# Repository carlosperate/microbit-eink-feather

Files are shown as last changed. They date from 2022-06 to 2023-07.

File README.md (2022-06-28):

# micro:bit eInk Feather Adaptor

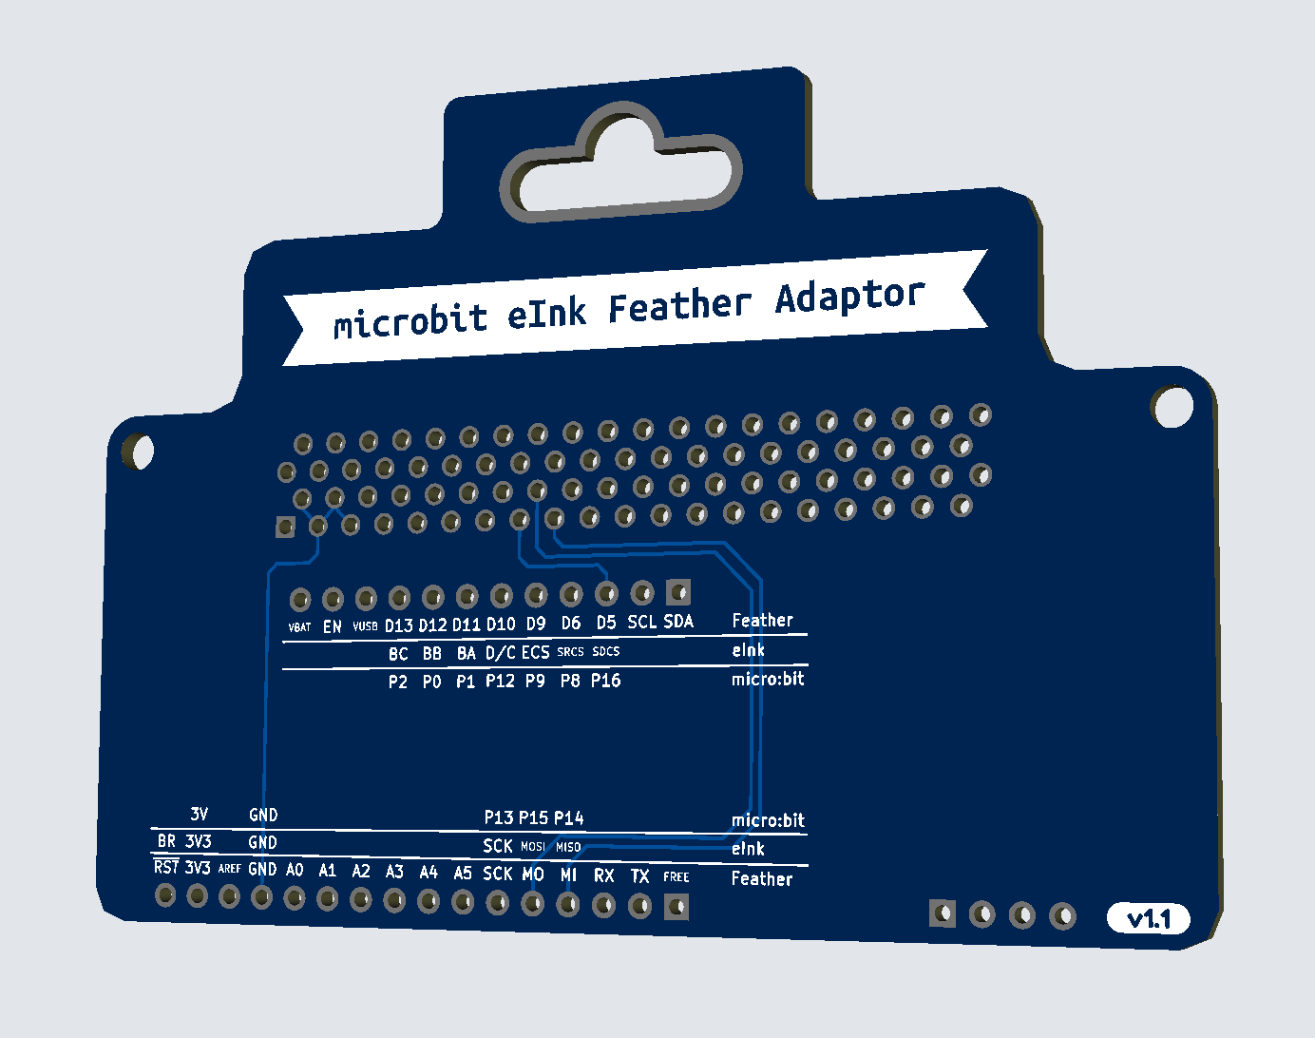
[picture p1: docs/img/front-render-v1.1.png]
front-render-v1 0


This is a simple FeatherWing to micro:bit adaptor board designed specifically
for the Adafruit 2.9" Grayscale eInk / ePaper Display FeatherWing:
https://www.adafruit.com/product/4777

## Repository Contents

- **datasheets**: Datasheets for the components used in this adaptor board
- **docs**: Documentation related to this adaptor board
- **firmware**: Arduino Skectch to test the eInk FeatherWing with a micro:bit
- **hardware**: The KiCad project files
- **output**: Project output files, like the BOM, schematic PDFs, etc.
    - **interactive_bom**: BOM output from the
      [Interactive HTML BOM](https://github.com/openscopeproject/InteractiveHtmlBom)
      KiCad plugin.
    - **pdf**: Schematic PDFs.
    - **production**: Gerber and drill files.

## Documentation

- Pinout connections for the adaptor board: [docs/pins.md](docs/pins.md)
- [eInk FeatherWing product page](https://www.adafruit.com/product/4777)
- [Adafruit documentation for the eInk FeatherWing](https://learn.adafruit.com/adafruit-eink-display-breakouts/grayscale-29-overview)
- [Documentation for the family of Adafruit 2.9" eInk Display Breakouts and FeatherWings](https://learn.adafruit.com/adafruit-2-9-eink-display-breakouts-and-featherwings/)
- Project Changelog: [CHANGELOG.md](CHANGELOG.md)

## License & Attributions

The Arduino test sketch is based on the
[Adafruit EDP ThinkInk_gray4 example][6], with [MIT License][7].

The micro:bit edge connector is [MIT Licensed][8] and comes from:
https://github.com/anthonykirby/kicad_microbit_connector

This project has been based on this FeatherWing template:
https://github.com/ppelleti/FeatherWing-template-KiCad

The FeatherWing template and the rest of the repository (except where stated
otherwise) is licensed under [the same terms as the KiCad libraries][9],
which is the [CC-BY-SA 4.0][10] license, with an exception that says that
electronic designs based on this repository are not bound by the attribution
and share-alike conditions.

[6]: https://github.com/adafruit/Adafruit_EPD/blob/4.4.3/examples/ThinkInk_gray4/ThinkInk_gray4.ino
[7]: firmware/eink_feather_test/LICENSE
[8]: hardware/microbit_connector/LICENSE
[9]: https://forum.kicad.info/t/kicad-library-licensing/7856
[10]: https://creativecommons.org/licenses/by-sa/4.0/legalcode

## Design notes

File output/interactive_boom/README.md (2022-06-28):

# Interactive BOM

This BOM has been created with the
[Interactive HTML BOM](https://github.com/openscopeproject/InteractiveHtmlBom)
plugin.

To preview this HTML online you can use this link:
[online ibom.min.html](https://refined-github-html-preview.kidonng.workers.dev/carlosperate/microbit-eink-feather/raw/main/output/interactive_boom/ibom.min.html)

The node `package.json` file contains an npm script to minify the output of
the plugin:
```
npm run minify
```

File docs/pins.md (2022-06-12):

# Pins

## Board Pin Routing

This table show the feather to micro:bit pins connections.

None of the micro:bit pins selected have other functionality (like the
matrix display or buttons). The P0, P1, and P2 micro:bit pins have weak pull
ups and so, they have been assigned to the eInk feather buttons, as that should
not affect their operation.

| Feather ⬅️ | eInk | micro:bit pin | | Feather ➡️ | eInk | micro:bit pin |
|---|---|---|-|---|---|---|
| RST | RST | - | | | | |
| 3.3V | 3V | - | | | | |
| Aref | - | - | | | | |
| GND | GND | - | | | | |
| A0 | - | - | | Bat | - | - |
| A1 | - | - | | En | - | - |
| A2 | - | - | | VUSB  | - | - |
| A3 | - | - | | D13 | C Button | P2 |
| A4 | - | - | | D12 | B Button | P0 |
| A5 | - | - | | D11 | A Button | P1 |
| SCK | SCK | P13 (SCK) | | D10 | D/C | P12 |
| MO | MOSI | P15 (MOSI) | | D9 | ECS | P9 |
| MI | MISO | P14 (MISO) | | D6 | SRCS | P8 |
| RX | - | - | | D5 | SDCS | P16 |
| TX | - | - | | SCL | - | - |
| Free | - | - | | SDA | - | - |

Feather pins:
- RST - Connected to the Reset button in the eInk feather
- SCK - SPI Clock
- MO - SPI MOSI from microcontroller to feather
- MI - SPI MISO from feather to microcontroller
- Button A/B/C - Connected to the three top button in the feather
- D/C - The eInk Data/Command pin, required for controlling the display
- ECS - Eink SPI Chip Select
- SRCS - SRAM SPI Chip Select
- SDCS - SD Card SPI Chip Select

eInk feather pinout from:
https://learn.adafruit.com/adafruit-eink-display-breakouts/pinouts-2

## Pinouts

This section contains the micro:bit V2 and Generic Feather pinouts for
reference.

### micro:bit V2 pinout

From: https://tech.microbit.org/hardware/edgeconnector/#edge-connector-pins

micro:bit pinout

### Feather pinout

This is the generic feather pinout, which might change slightly depending on
the board. From:
https://learn.adafruit.com/adafruit-feather/feather-specification#pin-naming-3096825-19

| Feather left header | Feather right header |
|---|---|
| Rst  | |
| 3.3V | |
| Aref | |
| GND  | |
| A0 | Bat  |
| A1 | En |
| A2 | VUSB |
| A3 | D13  |
| A4 | D12  |
| A5 | D11  |
| SCK  | D10  |
| MO | D9 |
| MI | D6 |
| RX | D5 |
| TX | SCL  |
| Free | SDA  |

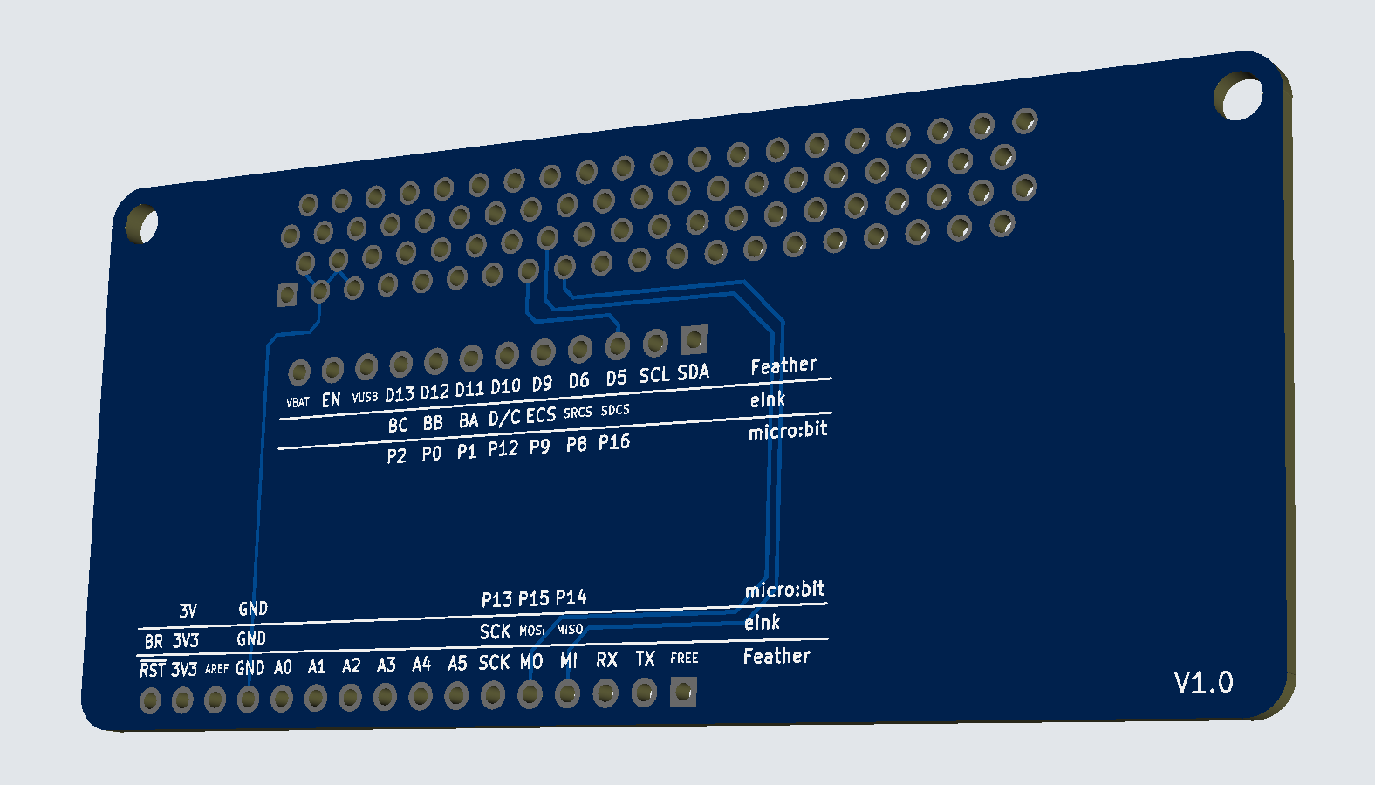
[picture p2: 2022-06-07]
docs/img/front-render-v1.0.png

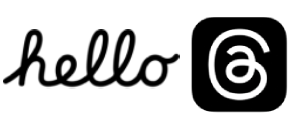
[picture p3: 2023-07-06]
firmware/eink_feather_sd_bmp/hello.bmp

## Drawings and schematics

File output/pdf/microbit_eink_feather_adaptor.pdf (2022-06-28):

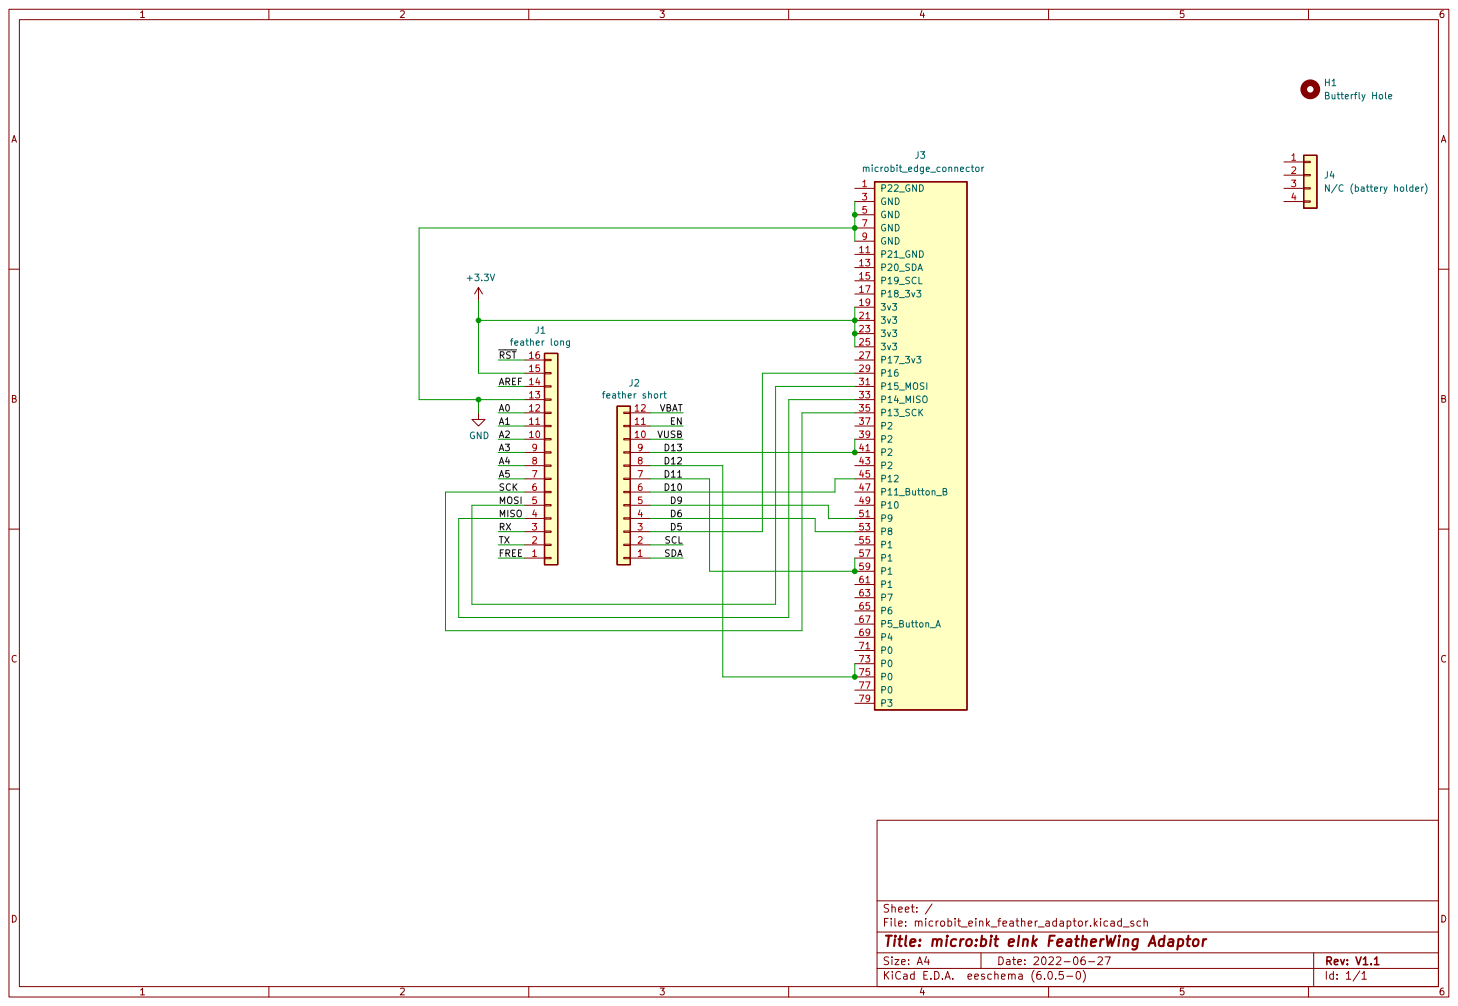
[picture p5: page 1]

File: microbit_eink_feather_adaptor.kicad_sch Sheet: /
Id: 1/1 Title: micro:bit eInk FeatherWing Adaptor

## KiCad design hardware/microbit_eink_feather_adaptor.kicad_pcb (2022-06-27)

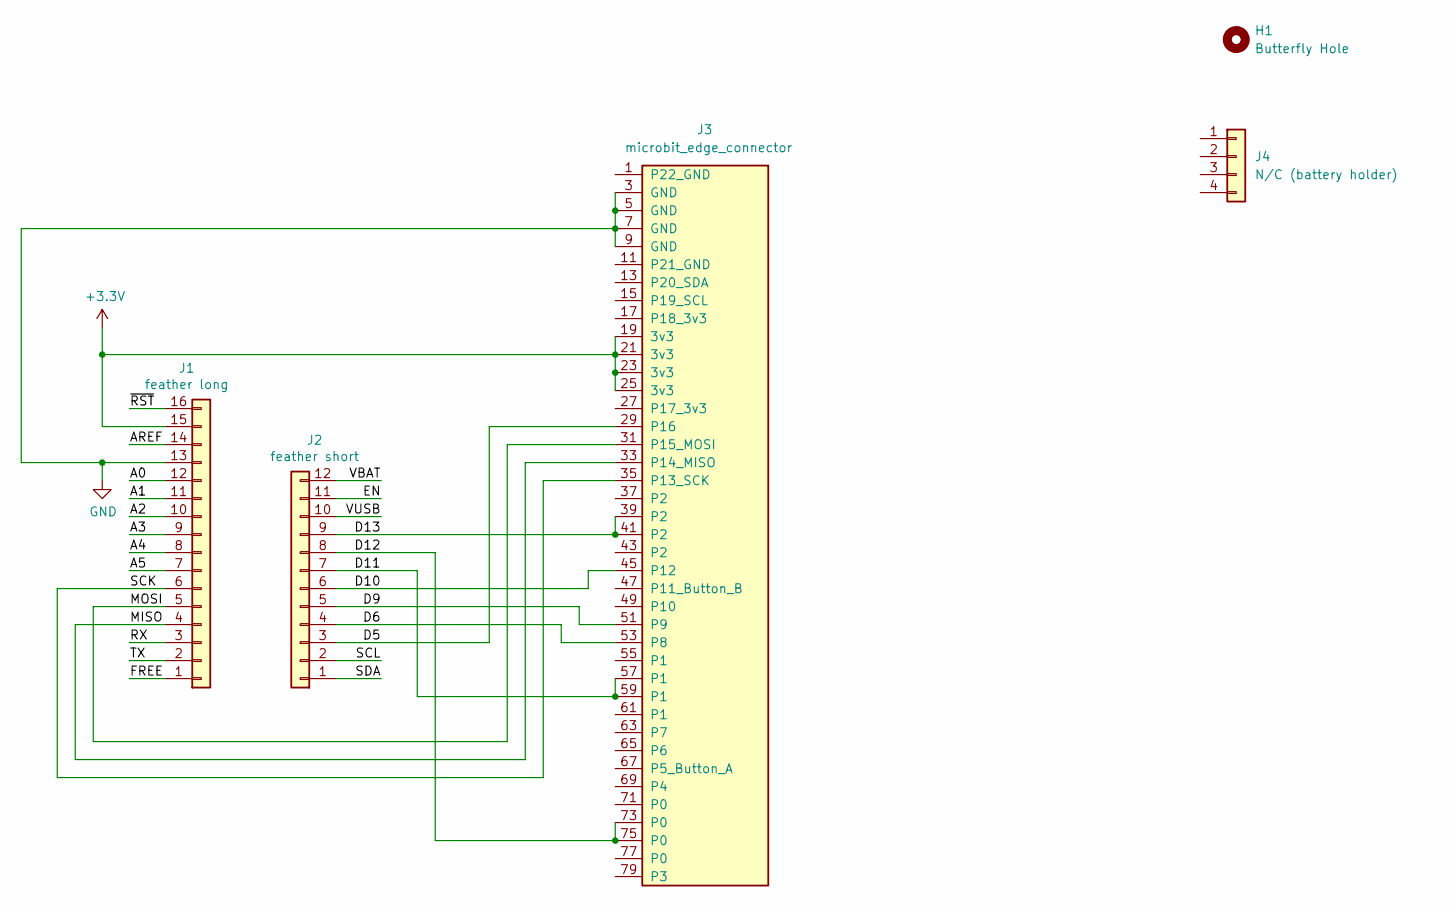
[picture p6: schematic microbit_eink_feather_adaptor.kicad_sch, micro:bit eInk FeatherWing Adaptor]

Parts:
H1: Butterfly Hole; butterfly_hole
J1: feather long; PinHeader_1x16_P2.54mm_Vertical
J2: feather short; PinHeader_1x12_P2.54mm_Vertical
J3: microbit_edge_connector; 4UCON_10156_2x40_P1.27mm_Socket_Horizontal
J4: N/C (battery holder); PinHeader_1x04_P2.54mm_Vertical

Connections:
+3V3: J1.15, J3.19 (3v3), J3.21 (3v3), J3.23 (3v3), J3.25 (3v3)
/A0: J1.12
/A1: J1.11
/A2: J1.10
/A3: J1.9
/A4: J1.8
/A5: J1.7
/AREF: J1.14
/D5: J2.3, J3.29 (P16)
/D6: J2.4, J3.53 (P8)
/D9: J2.5, J3.51 (P9)
/D10: J2.6, J3.45 (P12)
/D11: J2.7, J3.57 (P1), J3.59 (P1)
/D12: J2.8, J3.73 (P0), J3.75 (P0)
/D13: J2.9, J3.39 (P2), J3.41 (P2)
/EN: J2.11
/FREE: J1.1
/MISO: J1.4, J3.33 (P14_MISO)
/MOSI: J1.5, J3.31 (P15_MOSI)
/RX: J1.3
/SCK: J1.6, J3.35 (P13_SCK)
/SCL: J2.2
/SDA: J2.1
/TX: J1.2
/VBAT: J2.12
/VUSB: J2.10
/~RST: J1.16
GND: J1.13, J3.3 (GND), J3.5 (GND), J3.7 (GND), J3.9 (GND)

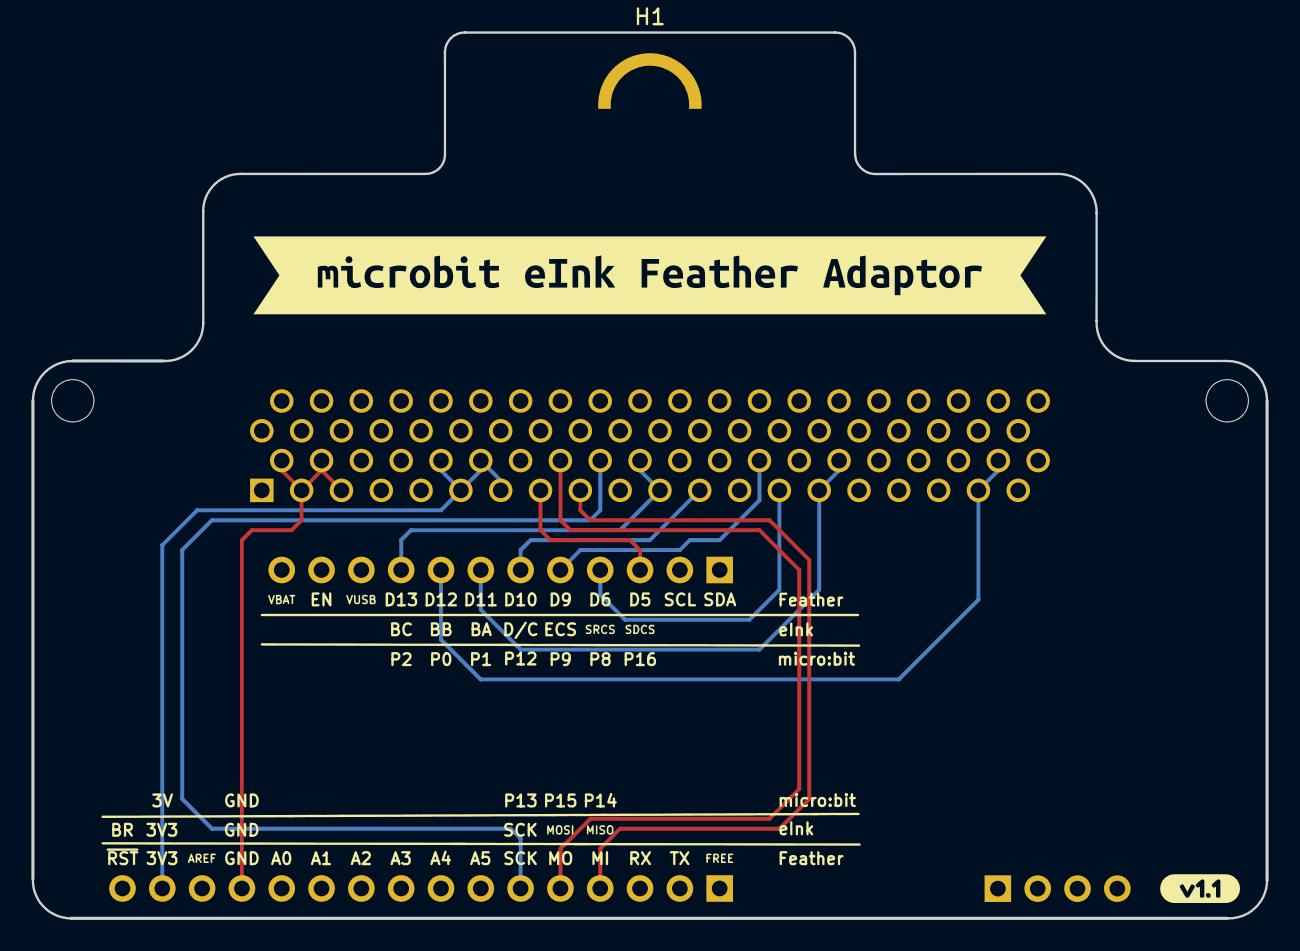
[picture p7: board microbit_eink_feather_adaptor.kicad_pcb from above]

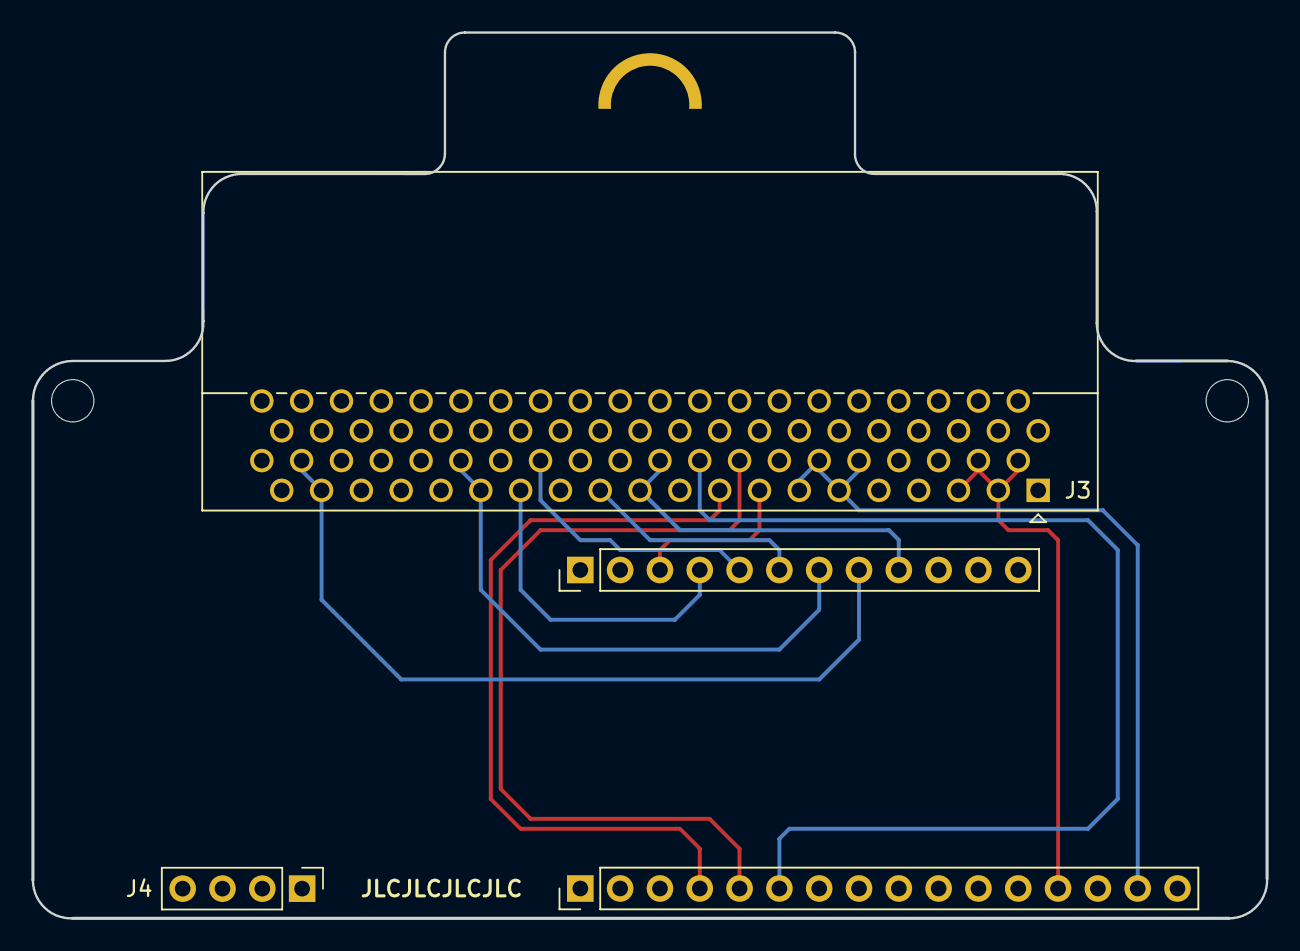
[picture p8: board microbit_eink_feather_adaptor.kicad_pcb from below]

Board: 2 copper layers, 78.7 x 56.5 mm, 7 parts (4 on the bottom side), 12 nets.

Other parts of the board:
kibuzzard-62B8B88C: G***; kibuzzard-62B8B88C
kibuzzard-62B89D05: G***; kibuzzard-62B89D05

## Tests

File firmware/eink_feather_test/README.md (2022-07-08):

# Arduino Test Sketch

This is an Arduino Sketch to run a test of the eInk FeatherWing connected to
a micro:bit V2 using the
[sandeepmistry/arduino-nRF5](https://github.com/sandeepmistry/arduino-nRF5/)
Arduino Core.

Dependencies:
- [Arduino IDE](https://www.arduino.cc/en/software)
- Arduino Core:
    - [Nordic Semiconductor nRF5 Boards by Sandeep Mistry](https://github.com/sandeepmistry/arduino-nRF5/) (v0.7.0 at the time of writing)
- Libraries:
    - [Adafruit EPD](https://github.com/adafruit/Adafruit_EPD) (v4.4.3 at the time of writing)
    - [Adafruit GFX Library](https://github.com/adafruit/Adafruit-GFX-Library/) (v1.11.1 at the time of writing)
        - This also brings [Adafruit BusIO](https://github.com/adafruit/Adafruit_BusIO) as a dependency (v1.11.6 at the time of writing)
    - [Adafruit microbit Library](https://github.com/adafruit/Adafruit_Microbit) (v1.3.1 at the time of writing)

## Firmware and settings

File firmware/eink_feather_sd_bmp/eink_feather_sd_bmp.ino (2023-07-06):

// Adafruit_ImageReader test for Adafruit E-Ink Breakouts.
// Demonstrates loading images from SD card or flash memory to the screen,
// to RAM, and how to query image file dimensions.
// Requires BMP file in root directory of QSPI Flash:
// hello.bmp.

#include <Adafruit_GFX.h>         // Core graphics library
#include "Adafruit_ThinkInk.h"
#include <SdFat.h>                // SD card & FAT filesystem library
#include <Adafruit_SPIFlash.h>    // SPI / QSPI flash library
#include <Adafruit_ImageReader_EPD.h> // Image-reading functions

// Comment out the next line to load from SPI/QSPI flash instead of SD card:
#define USE_SD_CARD 1

#define EPD_DC      12 // can be any pin, but required!
#define EPD_CS      9  // can be any pin, but required!
#define SRAM_CS     -1  // can set to -1 to not use a pin (uses a lot of RAM!)
#define EPD_BUSY    -1  // can set to -1 to not use a pin (will wait a fixed delay)
#define EPD_RESET   -1  // can set to -1 and share with chip Reset (can't deep sleep)
#define SD_CS       16  // SD card chip select

// Mono Displays
ThinkInk_290_Grayscale4_T5 display(EPD_DC, EPD_RESET, EPD_CS, SRAM_CS, EPD_BUSY);

// Filesystem
SdFat                    SD;         // SD card filesystem
Adafruit_ImageReader_EPD reader(SD); // Image-reader object, pass in SD filesys

// Image
Adafruit_Image_EPD   img;        // An image loaded into RAM

void setup(void) {

  ImageReturnCode stat; // Status from image-reading functions

  Serial.begin(9600);
  //while(!Serial);           // Wait for Serial Monitor before continuing

  display.begin();

  // The Adafruit_ImageReader constructor call (above, before setup())
  // accepts an uninitialized SdFat or FatVolume object. This MUST
  // BE INITIALIZED before using any of the image reader functions!
  Serial.print(F("Initializing filesystem..."));
  // SPI or QSPI flash requires two steps, one to access the bare flash
  // memory itself, then the second to access the filesystem within...

  // SD card is pretty straightforward, a single call...
  if(!SD.begin(SD_CS, SD_SCK_MHZ(10))) { // Breakouts require 10 MHz limit due to longer wires
    Serial.println(F("SD begin() failed"));
    for(;;); // Fatal error, do not continue
  }

  Serial.println(F("OK!"));

  // Load full-screen BMP file 'hello.bmp' at position (0,0) (top left).
  // Notice the 'reader' object performs this, with 'epd' as an argument.
  Serial.print(F("Loading hello.bmp to canvas..."));
  stat = reader.drawBMP((char *)"/hello.bmp", display, 0, 0);
  reader.printStatus(stat); // How'd we do?
  display.display();

  // Query the dimensions of image 'hello.bmp' WITHOUT loading to screen:
  int32_t width  = 0;
  int32_t height = 0;
  Serial.print(F("Querying hello.bmp image size..."));
  stat = reader.bmpDimensions("hello.bmp", &width, &height);
  reader.printStatus(stat);   // How'd we do?
  if(stat == IMAGE_SUCCESS) { // If it worked, print image size...
    Serial.print(F("Image dimensions: "));
    Serial.print(width);
    Serial.write('x');
    Serial.println(height);
  }

  delay(30 * 1000); // Pause 30 seconds before continuing because it's eInk

  Serial.print(F("Drawing canvas to EPD..."));
  display.clearBuffer();

  // Load small BMP 'hello.bmp' into a GFX canvas in RAM. This should fail
  // gracefully on Arduino Uno and other small devices, meaning the image
  // will not load, but this won't make the program stop or crash, it just
  // continues on without it. Should work on larger ram boards like M4, etc.
  stat = reader.loadBMP("/hello.bmp", img);
  reader.printStatus(stat); // How'd we do?
}

void loop() {
  for(int r=0; r<4; r++) {     // For each of 4 rotations...
    display.setRotation(r);    // Set rotation
    display.fillScreen(0);     // and clear screen
    display.clearBuffer();
    img.draw(display, 0, 0);
    display.display();
    delay(30 * 1000); // Pause 30 sec.
  }
}

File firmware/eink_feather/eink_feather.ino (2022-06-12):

/* 
 * This test file has been modified from Adafruit's EDP library
 * ThinkInk_tricolor.ino example.
 */
/***************************************************
  Adafruit invests time and resources providing this open source code,
  please support Adafruit and open-source hardware by purchasing
  products from Adafruit!

  Written by Limor Fried/Ladyada for Adafruit Industries.
  MIT license, all text above must be included in any redistribution
 ****************************************************/
#include "Adafruit_ThinkInk.h"

#define EPD_DC      12  // eInk Data/Command pin
#define EPD_CS       9  // eInk Chip Select
#define EPD_BUSY    -1  // eInk Busy signa, not wired, set to -1 (waits a fixed delay)
#define SRAM_CS     -1  // 8 // SRAM Chip Select, can be set to -1 store buffer in uC RAM 
#define EPD_RESET   -1  // can set to -1 and share with chip Reset (can't deep sleep)

// 2.9" Grayscale Featherwing
ThinkInk_290_Grayscale4_T5 display(EPD_DC, EPD_RESET, EPD_CS, SRAM_CS, EPD_BUSY);

#define DELAY_BETWEEN_TESTS (5000)

void setup() {
  Serial.begin(115200);
  while (!Serial) {
    delay(10);
  }
  Serial.println("Adafruit EPD full update test in mono & grayscale");
}

bool gray = true;
void loop() {
  gray = !gray;

  // alternate modes!
  if (gray) {
    display.begin(THINKINK_GRAYSCALE4);
    Serial.println("Grayscale!");
  } else {
    display.begin(THINKINK_MONO);
    Serial.println("Monochrome!");
  }

  // Show the mode in the eInk Display
  display.clearBuffer();
  display.setTextSize(3);
  display.setTextColor(EPD_BLACK);
  display.setCursor(20, 40);
  display.print(gray ? "Grayscale": "Monochrome");
  display.display();

  delay(DELAY_BETWEEN_TESTS);

  // Draw squares with each of the available colours
  display.clearBuffer();
  display.fillRect((display.width() * 1) / 4, 0, display.width() / 4, display.height(), EPD_LIGHT);
  display.fillRect((display.width() * 2) / 4, 0, display.width() / 4, display.height(), EPD_DARK);
  display.fillRect((display.width() * 3) / 4, 0, display.width() / 4, display.height(), EPD_BLACK);
  display.display();

  delay(DELAY_BETWEEN_TESTS);

  // Large block of text
  Serial.println("Text demo");
  display.clearBuffer();
  display.setTextSize(2);
  testdrawtext("Lorem ipsum dolor sit amet, consectetur adipiscing elit. "
               "Curabitur adipiscing ante sed nibh tincidunt feugiat. "
               "Maecenas enim massa, fringilla sed malesuada et, malesuada sit amet turpis.", EPD_BLACK);
  display.display();

  delay(DELAY_BETWEEN_TESTS);

  // Rotating lines in half a sqaure and solid colours in the other half
  display.clearBuffer();
  for (int16_t i = 0; i < display.width(); i += 4) {
    display.drawLine(0, 0, i, display.height() - 1, EPD_BLACK);
  }
  for (int16_t i = 0; i < display.height(); i += 4) {
    display.drawLine(display.width() - 1, 0, 0, i, EPD_LIGHT); // on grayscale this will be mid-gray
  }
  display.display();
  
  delay(DELAY_BETWEEN_TESTS);
}

void testdrawtext(const char *text, uint16_t color) {
  display.setCursor(0, 0);
  display.setTextColor(color);
  display.setTextWrap(true);
  display.print(text);
}

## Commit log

2022-06-05 Add origin "FeatherWing_KC5" project before editing it.
    [microbit_eink_feather_adaptor.kicad_pcb, microbit_eink_feather_adaptor.sch]
2022-06-06 Update project from KiCARd 5 to 6.
    [microbit_eink_feather_adaptor.kicad_pcb, microbit_eink_feather_adaptor.kicad_sch, microbit_eink_feather_adaptor.sch]
2022-06-06 Add micro:bit edge connector to project.
    [microbit_eink_feather_adaptor.kicad_pcb, microbit_eink_feather_adaptor.kicad_sch]
2022-06-06 Increase board size, place edge connector, and route 3V, GND, and SPI pins.
    [microbit_eink_feather_adaptor.kicad_pcb, microbit_eink_feather_adaptor.kicad_sch]
2022-06-06 Add datasheet for the micro:bit edge connector.
2022-06-07 Route all pins and complete initial version of board.
    [microbit_eink_feather_adaptor.kicad_pcb, microbit_eink_feather_adaptor.kicad_sch]
2022-06-07 Add production files for manufacturing of initial V1.0
    [microbit_eink_feather_adaptor-B_Cu.gbl, microbit_eink_feather_adaptor-B_Mask.gbs, microbit_eink_feather_adaptor-B_Silkscreen.gbo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]
2022-06-12 fw: Add a test Arduino Sketch.
2022-06-12 ci: Add GitHub Action to compile Arduino test Sketch.
2022-06-12 docs: Minor updates to pin info and README.
2022-06-12 ci: Add Arduino Link job to Arduino workflow.
2022-06-26 output: Add output directory for schematic PDFs
2022-06-27 pcb: Expand PCB to include butterfly hang hole.
    [microbit_eink_feather_adaptor.kicad_pcb, microbit_eink_feather_adaptor.kicad_sch]
2022-06-27 pcb: Replace butterfly hole with custom footprint.
    [microbit_eink_feather_adaptor.kicad_pcb, microbit_eink_feather_adaptor.kicad_sch]
2022-06-27 schematic & pcb: Add (optional) header to physically hold battery.
    [microbit_eink_feather_adaptor.kicad_pcb, microbit_eink_feather_adaptor.kicad_sch]
2022-06-27 output: Add BOM & mode production folder inside output.
    [microbit_eink_feather_adaptor-B_Cu.gbl, microbit_eink_feather_adaptor-B_Mask.gbs, microbit_eink_feather_adaptor-B_Silkscreen.gbo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]
2022-06-27 production: Update gerber and drill files for v1.1 build.
    [microbit_eink_feather_adaptor-B_Cu.gbl, microbit_eink_feather_adaptor-B_Mask.gbs, microbit_eink_feather_adaptor-B_Silkscreen.gbo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]
2022-06-28 schematic: Update PDF output to v1.1 version.
2022-06-28 docs: Add image of v1.1 to README and README to BOM folder.
2022-07-08 fw: Add micro:bit Arduino library as dependency.
